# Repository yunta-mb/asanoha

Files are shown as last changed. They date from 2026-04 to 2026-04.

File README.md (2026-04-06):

# Asanoha keyboard
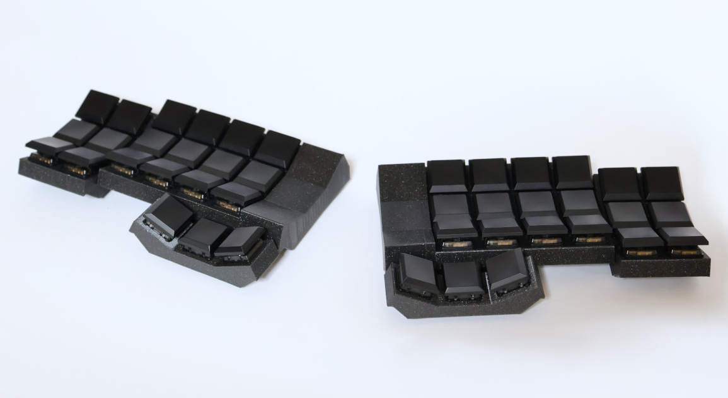
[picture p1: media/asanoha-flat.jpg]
Asanoha Keyboard with flat keycaps


## Features:
* ZMK
* XIAO BLE (nRF52840)
* Bluetooth and/or USB
* Wireless split
* 42 sockets for Kailh Choc
* Every switch has its own GPIO - no matrix scanning needed, just interrupts
* Light af
* Low profile
* True well (not just raised keycaps), with customizable angle 
* Hardware power switch
* FDM-printable chassis
* Works for months on a single charge

## Building firmware

In devcontainer:
```
west update
west build -p -b xiao_ble -S studio-rpc-usb-uart   -- -DSHIELD=asanoha_left  -DZMK_EXTRA_MODULES=/workspaces/zmk-modules/zmk-keyboard-asanoha/
west build -p -b xiao_ble -S studio-rpc-usb-uart   -- -DSHIELD=asanoha_right -DZMK_EXTRA_MODULES=/workspaces/zmk-modules/zmk-keyboard-asanoha/
```

## More photos
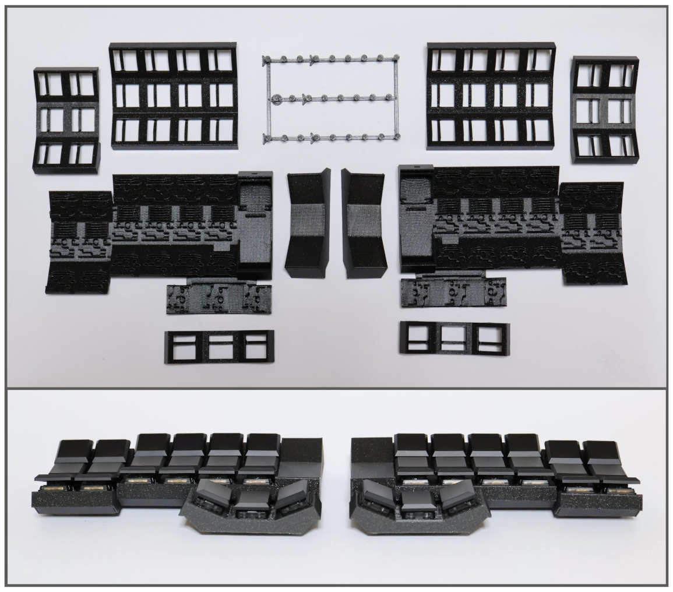
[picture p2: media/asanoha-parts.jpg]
Asanoha Keyboard printed parts

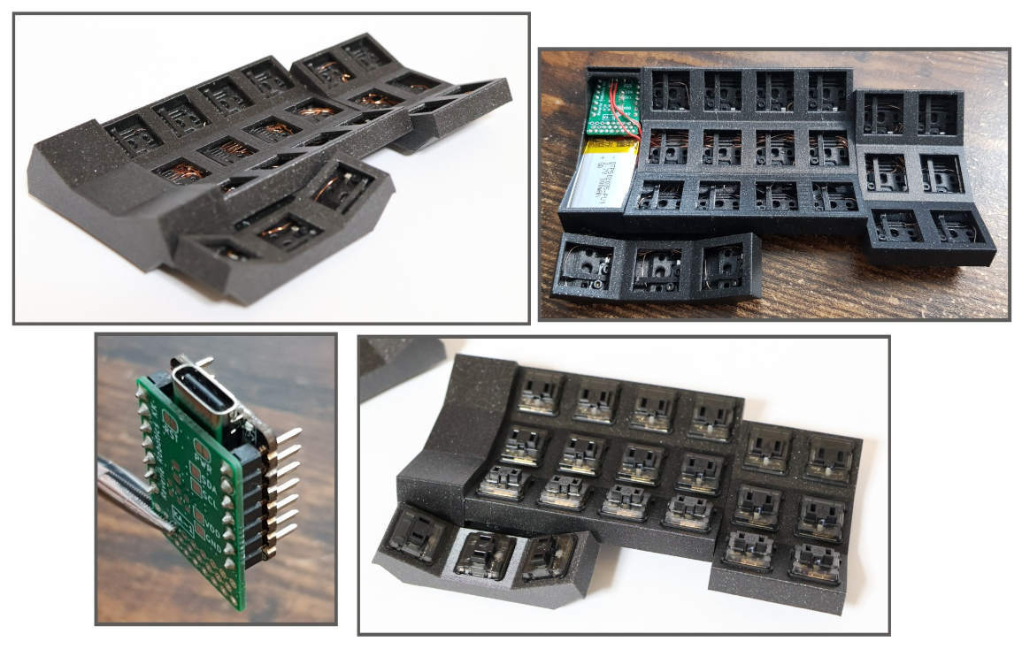
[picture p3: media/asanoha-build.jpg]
Asanoha Keyboard internal build

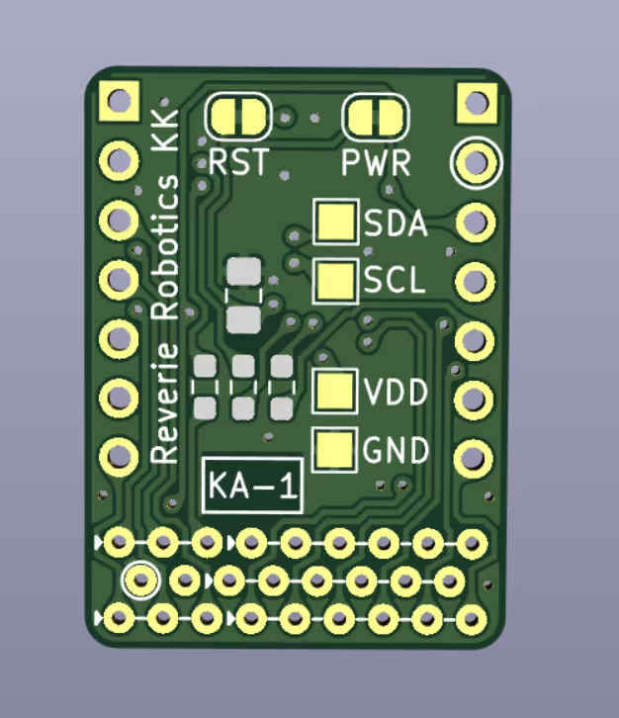
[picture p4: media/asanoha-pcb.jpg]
Asanoha Keyboard PCB drawing

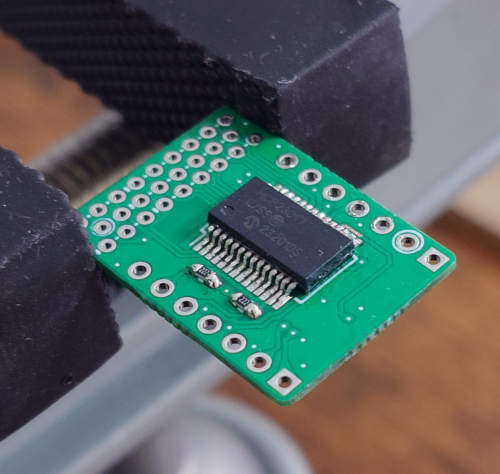
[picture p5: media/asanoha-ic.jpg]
Asanoha Keyboard IC photo

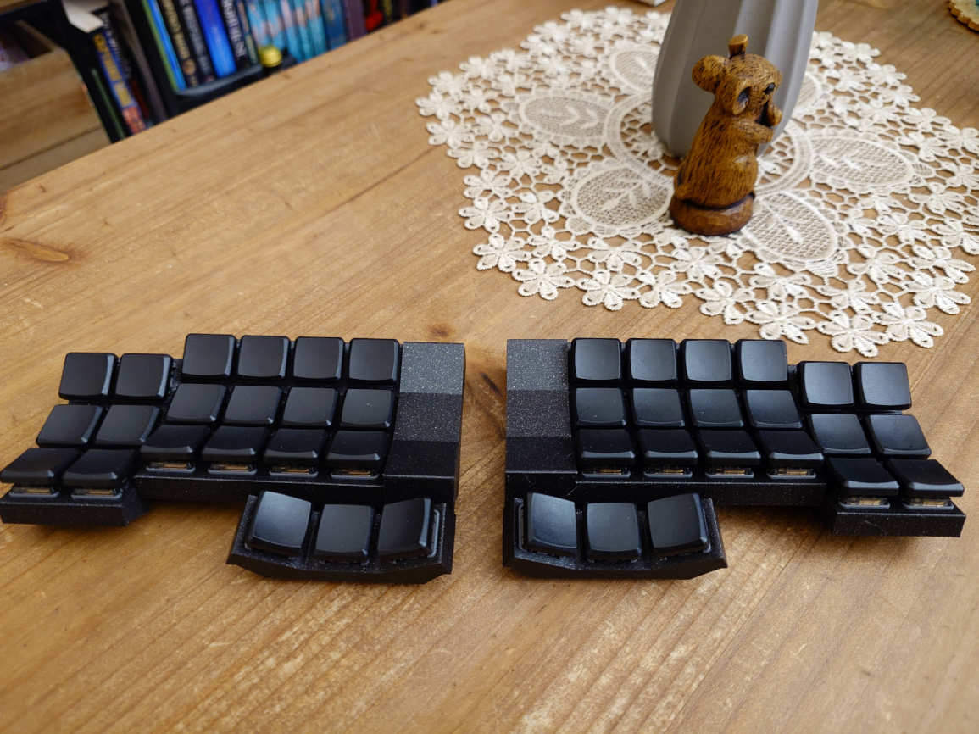
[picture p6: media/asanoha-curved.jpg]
Asanoha Keyboard with curved keycaps


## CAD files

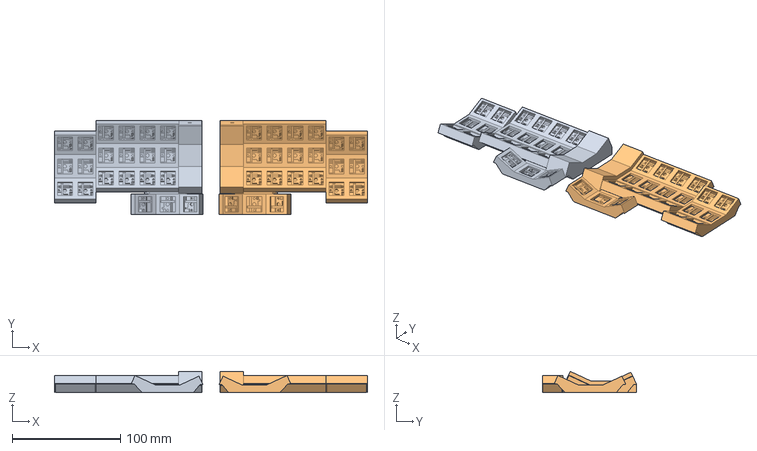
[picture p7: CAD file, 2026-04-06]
chassis/assembly.FCStd
288.6 x 86.9 x 19.7 mm
left
right

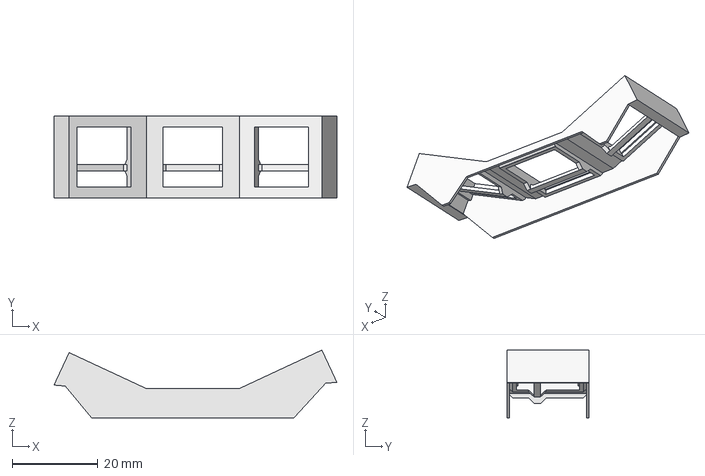
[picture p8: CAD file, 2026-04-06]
chassis/right-top-column-t.FCStd
66.0 x 19.1 x 15.8 mm

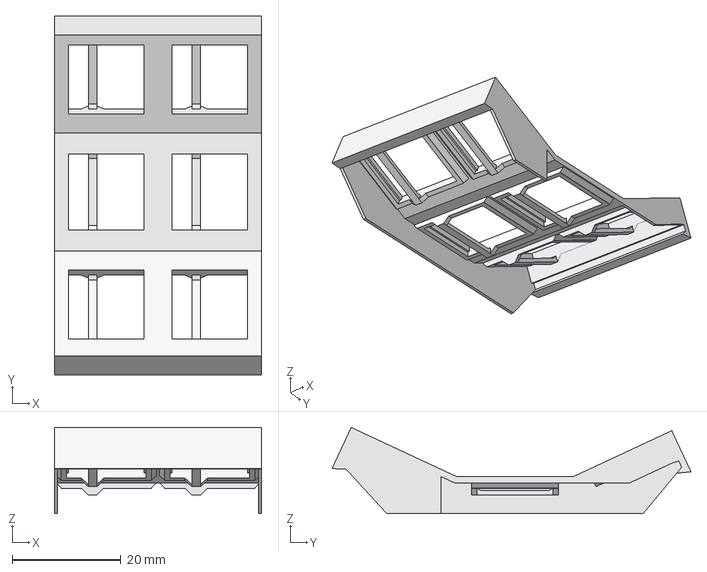
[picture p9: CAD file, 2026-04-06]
chassis/left-top-columns-5-6.FCStd
38.1 x 66.0 x 15.8 mm

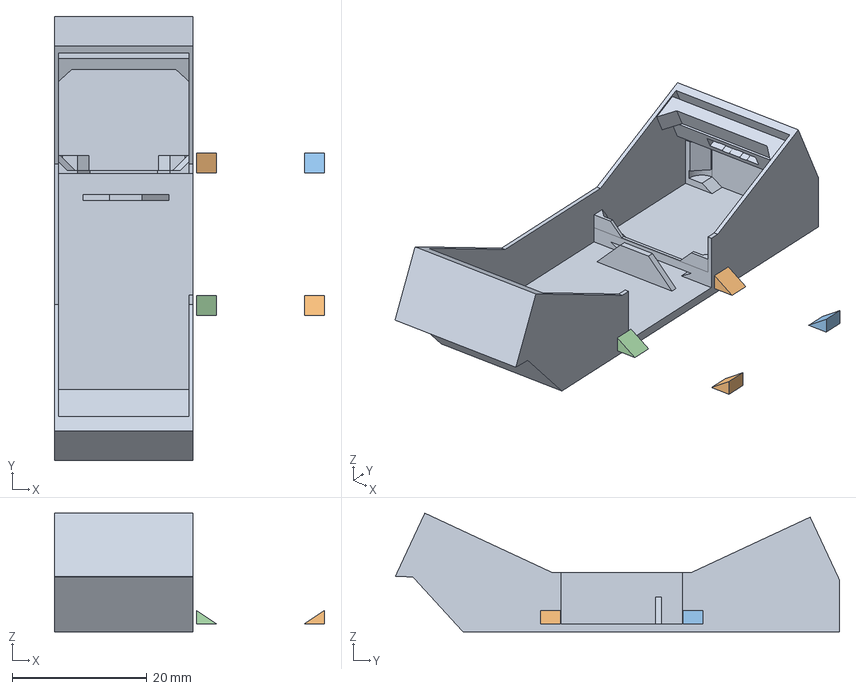
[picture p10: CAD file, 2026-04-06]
chassis/column.FCStd
40.1 x 66.0 x 17.6 mm
binder_tl_base x 2
binder_tr
binder_bl

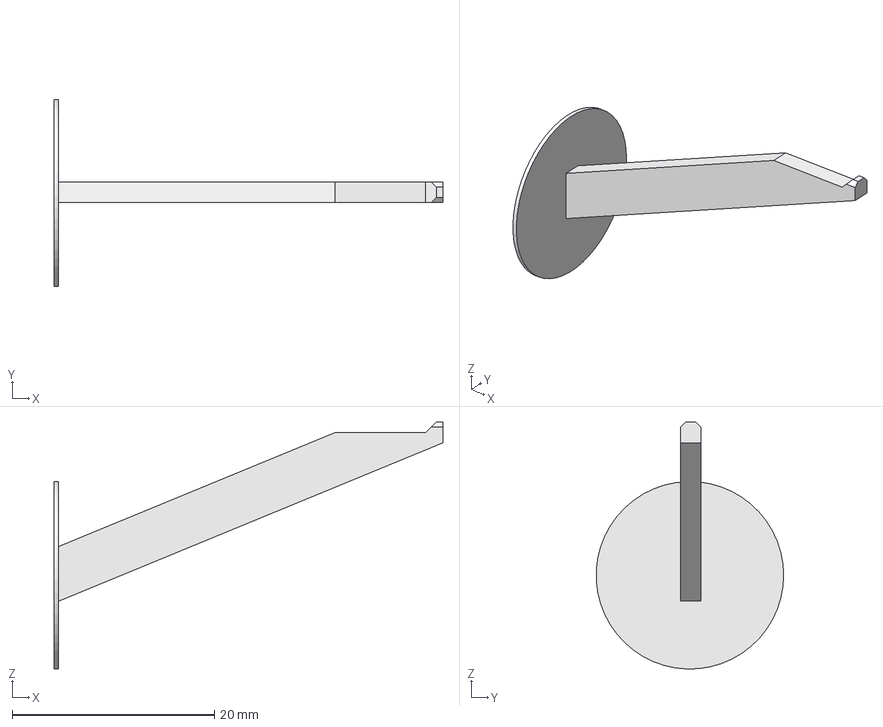
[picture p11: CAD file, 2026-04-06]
chassis/columns-1-4-support.FCStd
38.5 x 18.5 x 24.4 mm

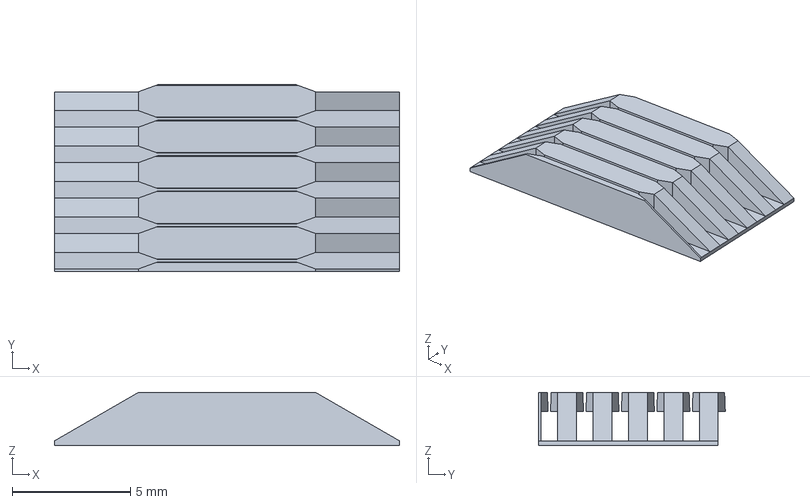
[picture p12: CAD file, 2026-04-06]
chassis/wire-guide-3.FCStd
14.6 x 7.90 x 2.25 mm

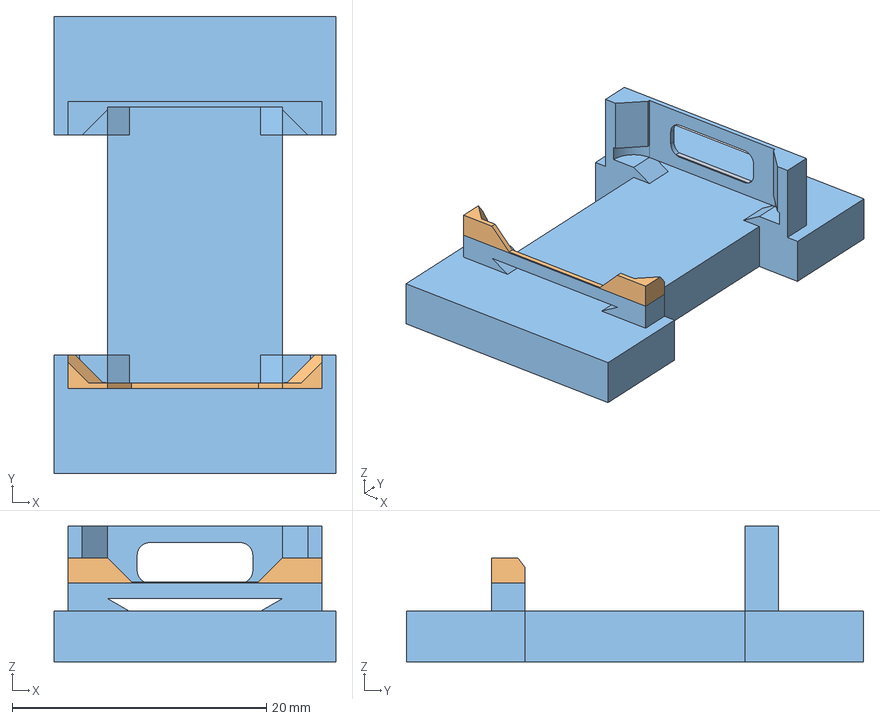
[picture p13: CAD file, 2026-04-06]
chassis/xiao-holder.FCStd
22.2 x 36.0 x 10.7 mm
above-pcb-rear
prototyping-holder

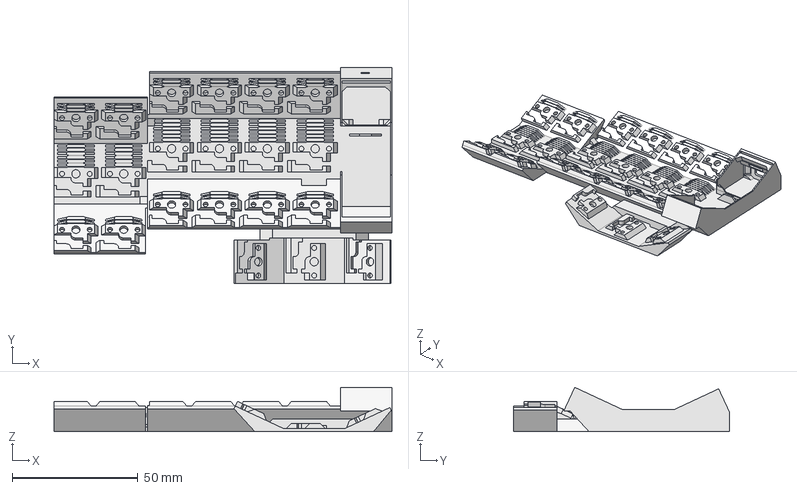
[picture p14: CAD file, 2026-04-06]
chassis/left-bottom.FCStd
134.6 x 86.1 x 17.6 mm

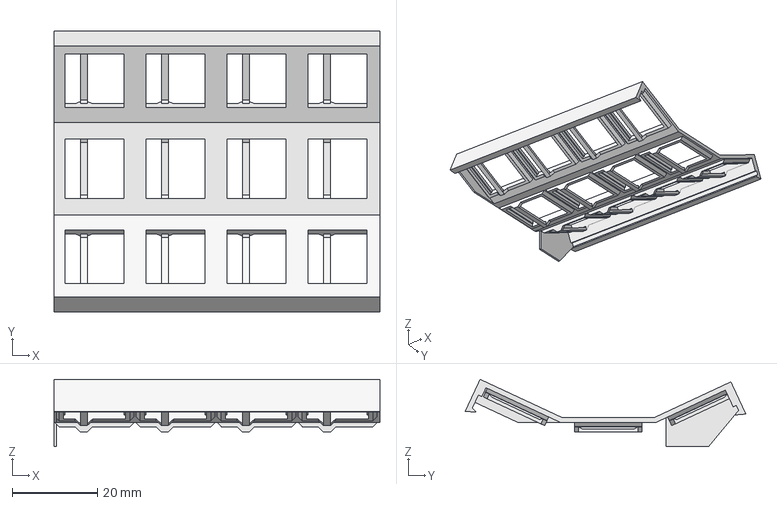
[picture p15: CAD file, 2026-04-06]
chassis/left-top-columns-1-4.FCStd
76.7 x 66.0 x 15.8 mm

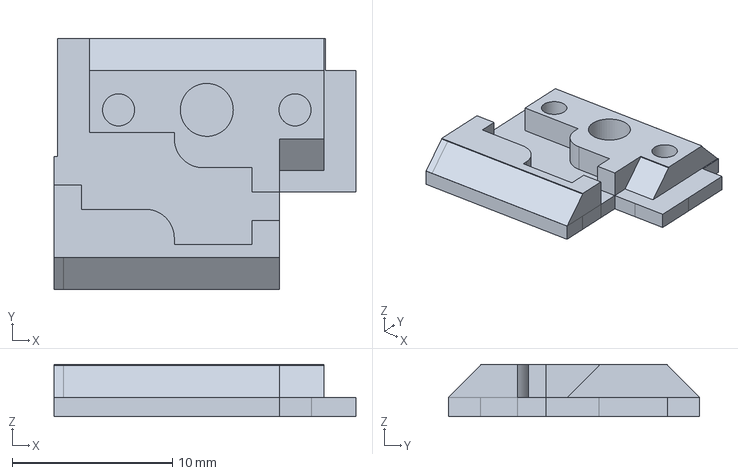
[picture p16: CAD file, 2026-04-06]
chassis/socket.FCStd
18.8 x 15.6 x 3.25 mm

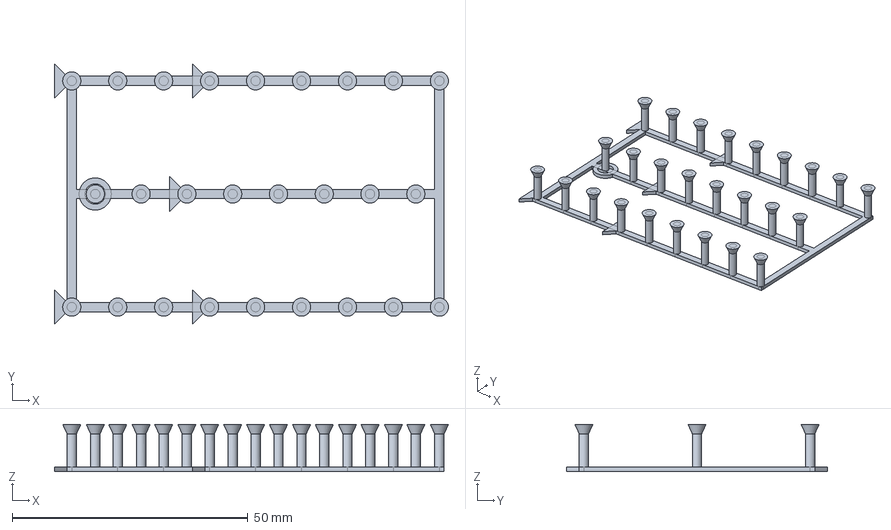
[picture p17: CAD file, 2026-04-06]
chassis/wiring-tool.FCStd
83.6 x 55.3 x 10.0 mm

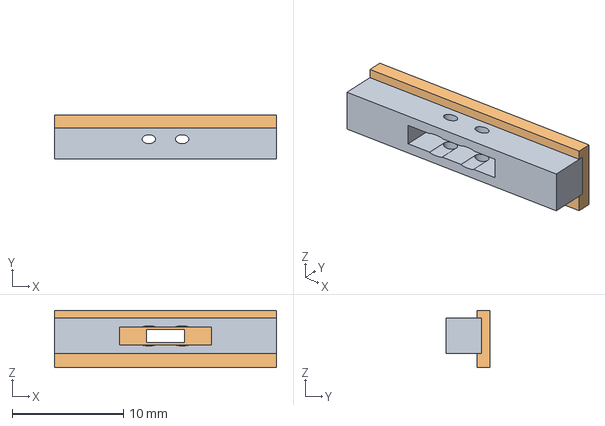
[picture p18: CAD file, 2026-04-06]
chassis/switch-holder.FCStd
20.0 x 4.00 x 5.18 mm
switch-holder-beam

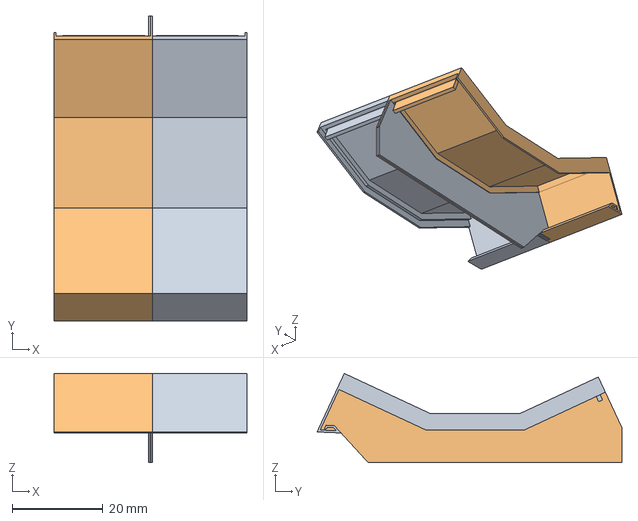
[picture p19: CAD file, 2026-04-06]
chassis/lid-3.FCStd
42.5 x 67.2 x 19.7 mm
lid-right
lid-left

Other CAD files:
chassis/dimensions.FCStd
chassis/right-bottom.FCStd
chassis/left-top-column-t.FCStd
chassis/right-top-columns-1-4.FCStd
chassis/right-top-columns-5-6.FCStd

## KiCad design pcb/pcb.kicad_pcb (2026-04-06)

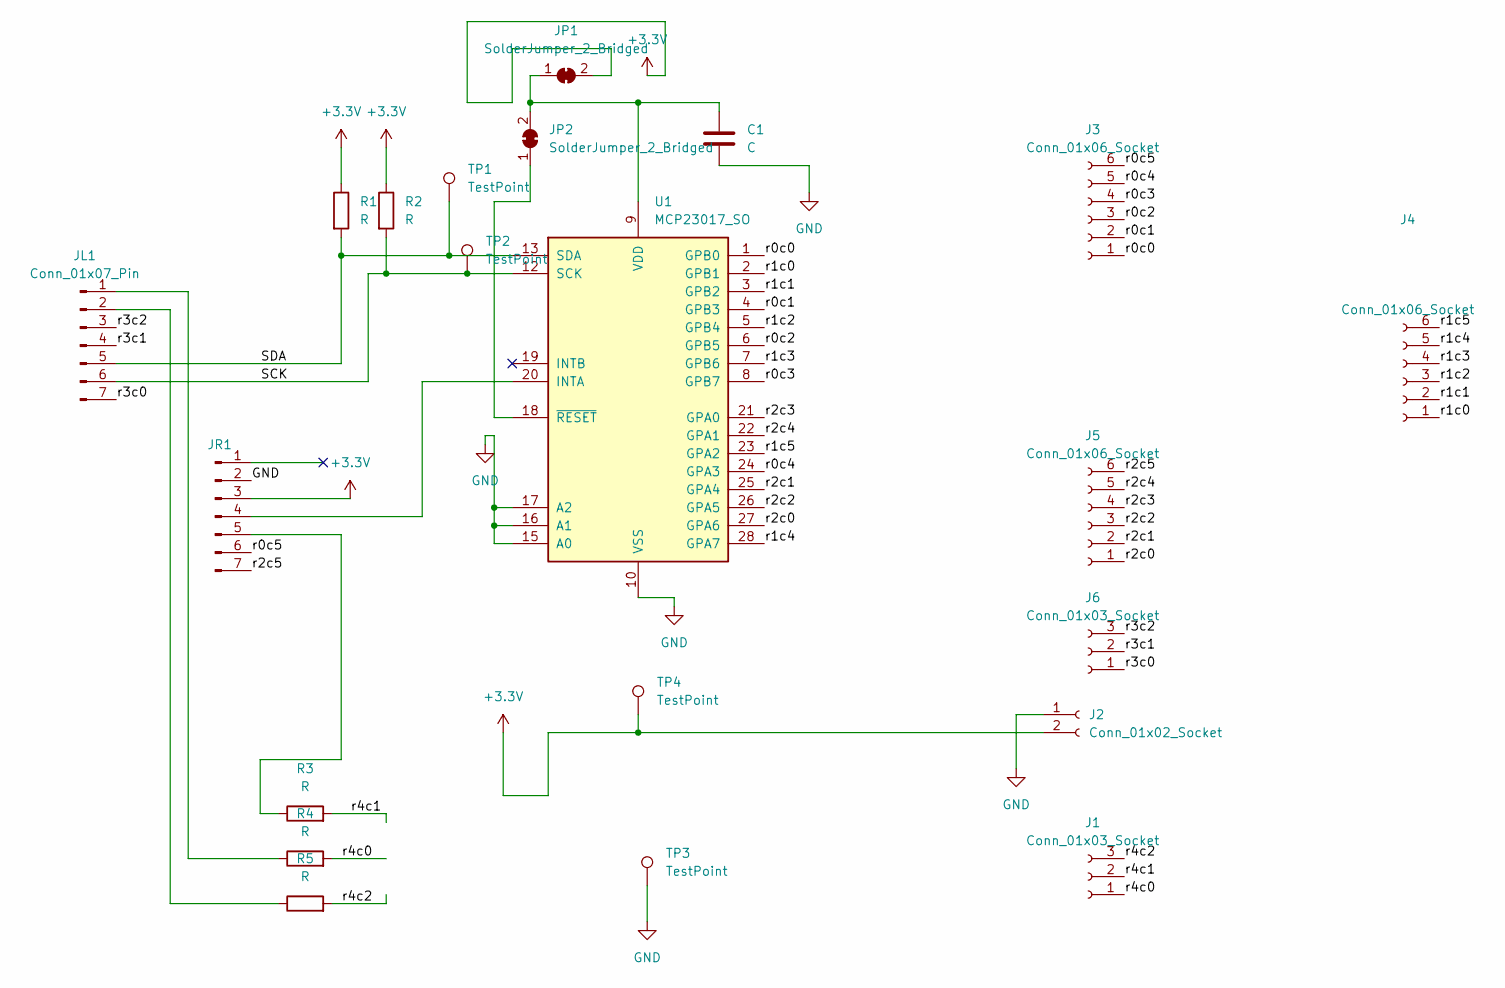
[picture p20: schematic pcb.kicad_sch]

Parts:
C1: C; C_0805_2012Metric_Pad1.18x1.45mm_HandSolder
J1, J6: Conn_01x03_Socket; SolderWire-0.1sqmm_1x03_P3.6mm_D0.4mm_OD1mm-dense-row-1
J2: Conn_01x02_Socket; SolderWire-0.1sqmm_1x02_P3.6mm_D0.4mm_OD1mm-dense-1
J3, J4, J5: Conn_01x06_Socket; SolderWire-0.1sqmm_1x06_P3.6mm_D0.4mm_OD1mm-dense-row-1
JL1: Conn_01x07_Pin; PinHeader_1x07_P2.54mm_Vertical-no-frame
JP1, JP2: SolderJumper_2_Bridged; SolderJumper-2_P1.3mm_Bridged_RoundedPad1.0x1.5mm
JR1: Conn_01x07_Pin; PinHeader_1x07_P2.54mm_Vertical-no-frame
R1, R2, R3, R4, R5: R; R_0603_1608Metric_Pad0.98x0.95mm_HandSolder
TP1, TP2, TP3, TP4: TestPoint; TestPoint_Pad_1.5x1.5mm
U1: MCP23017_SO; SSOP-28_5.3x10.2mm_P0.65mm

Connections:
+3.3V: J2.2, JP1.2 (B), JR1.3, R1.1, R2.1, TP4.1
/SCK: JL1.6, R2.2, TP2.1, U1.12 (SCK)
/SDA: JL1.5, R1.2, TP1.1, U1.13 (SDA)
/r0c0: J3.1, U1.1 (GPB0)
/r0c1: J3.2, U1.4 (GPB3)
/r0c2: J3.3, U1.6 (GPB5)
/r0c3: J3.4, U1.8 (GPB7)
/r0c4: J3.5, U1.24 (GPA3)
/r0c5: J3.6, JR1.6
/r1c0: J4.1, U1.2 (GPB1)
/r1c1: J4.2, U1.3 (GPB2)
/r1c2: J4.3, U1.5 (GPB4)
/r1c3: J4.4, U1.7 (GPB6)
/r1c4: J4.5, U1.28 (GPA7)
/r1c5: J4.6, U1.23 (GPA2)
/r2c0: J5.1, U1.27 (GPA6)
/r2c1: J5.2, U1.25 (GPA4)
/r2c2: J5.3, U1.26 (GPA5)
/r2c3: J5.4, U1.21 (GPA0)
/r2c4: J5.5, U1.22 (GPA1)
/r2c5: J5.6, JR1.7
/r3c0: J6.1, JL1.7
/r3c1: J6.2, JL1.4
/r3c2: J6.3, JL1.3
/r4c0: J1.1, R4.2
/r4c1: J1.2, R3.2
/r4c2: J1.3, R5.2
GND: C1.2, J2.1, JR1.2, TP3.1, U1.10 (VSS), U1.15 (A0), U1.16 (A1), U1.17 (A2)
unnamed: JL1.1, R4.1
unnamed: JL1.2, R5.1
unnamed: C1.1, JP1.1 (A), JP2.2 (B), U1.9 (VDD)
unnamed: JP2.1 (A), U1.18 (~RESET)
unnamed: JR1.4, U1.20 (INTA)
unnamed: JR1.5, R3.1

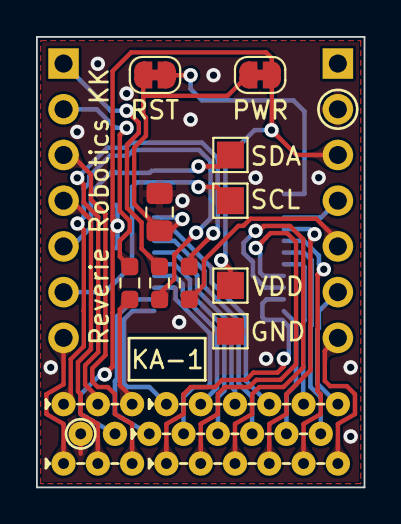
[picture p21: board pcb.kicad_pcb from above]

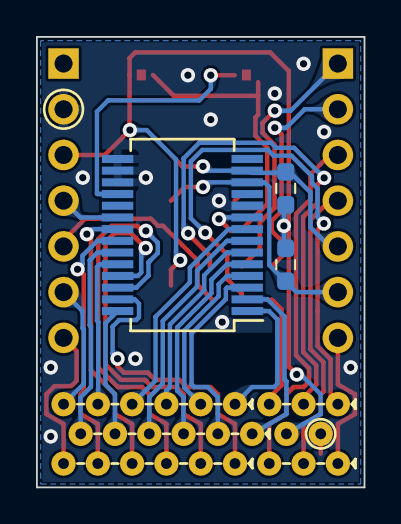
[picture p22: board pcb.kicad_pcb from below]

Board: 2 copper layers, 18.2 x 25.0 mm, 21 parts (5 on the bottom side), 34 nets.
